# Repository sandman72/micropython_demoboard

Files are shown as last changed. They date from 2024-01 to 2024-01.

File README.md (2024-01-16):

# MicroPython DemoBoard
This repo contains all necessary files for our MicroPython Hardware Workshop at the Attraktor e.V. Makerspace in Hamburg, Germany

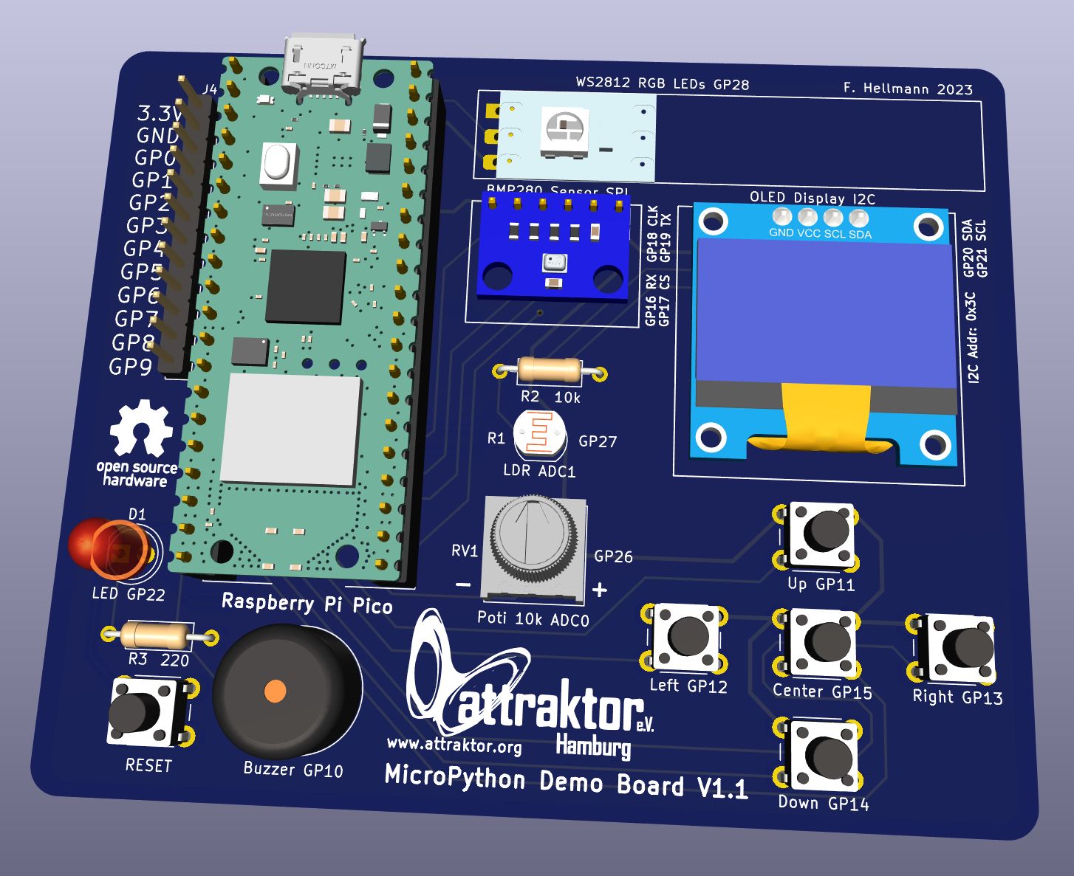
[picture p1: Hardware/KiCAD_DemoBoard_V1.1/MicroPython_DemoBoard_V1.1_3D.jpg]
DemoBoard 3D


You can find the workshop documentation in German here: <a href="https://wiki.attraktor.org/Micropython_Kurs_2023"> Attraktor MicroPython Workshop </a>

### Hardware:
The demoboard works with a Raspberry Pi Pico WH plugged into the pinheaders and connects it to various sensors, buttons, LEDs and an OLED display.

There are two hardware revision to date:

Version 1.0 is the initial version which used an older style of OLED Display with VCC and GND on pins 1 and 2. 

As these old style displays are hard to come by Version 1.1 was spun to change to GND and VCC on pins 1 and 2 as this is a more commonly found pinout of the OLED displays.

I would recommend to use Version 1.1 for all new boards.

You can find an interactive BOM (Bill of Material) here: <a href="https://raw.githack.com/sandman72/micropython_demoboard/main/Hardware/KiCAD_DemoBoard_V1.1/MicroPython_DemoBoard_V1.1_iBOM.html" traget="_blank"> iBOM </a>

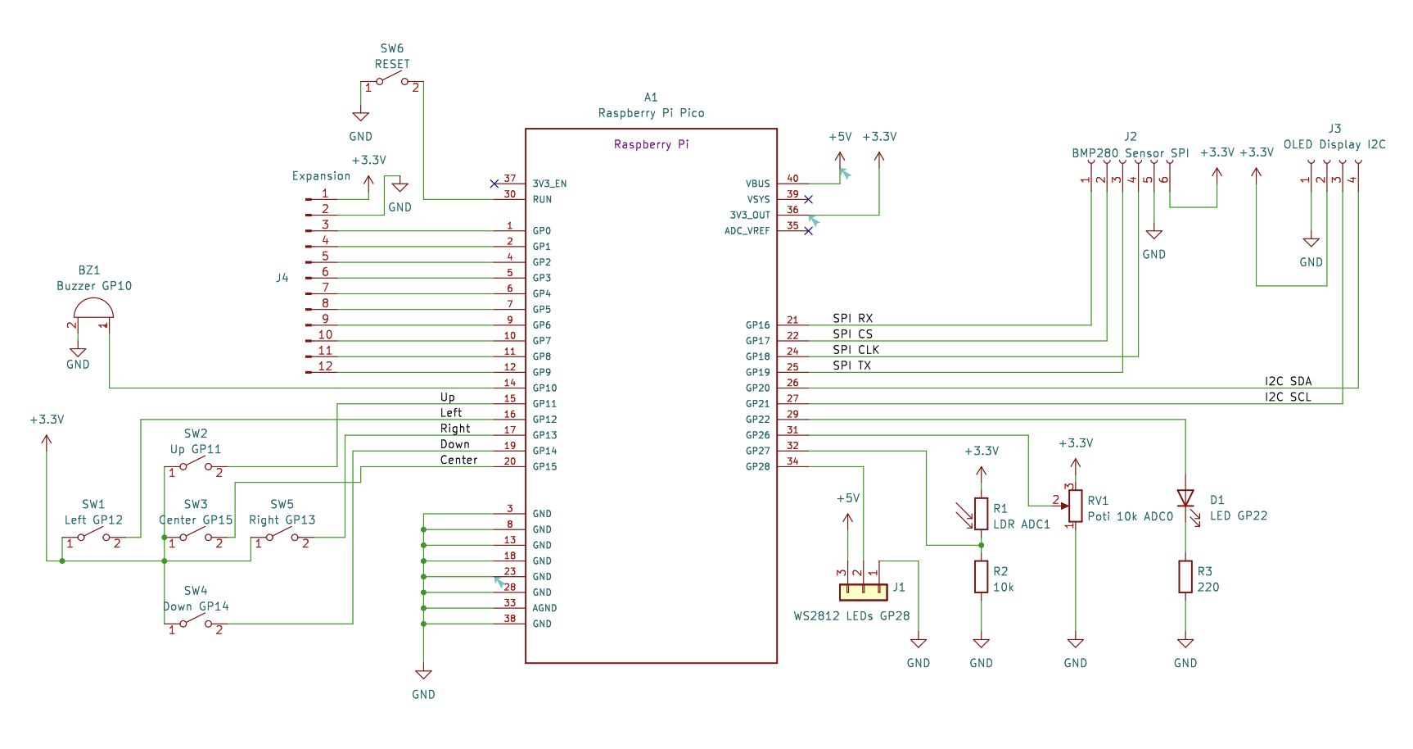
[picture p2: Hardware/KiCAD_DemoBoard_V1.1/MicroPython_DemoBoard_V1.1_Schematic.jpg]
DemoBoard Schematic

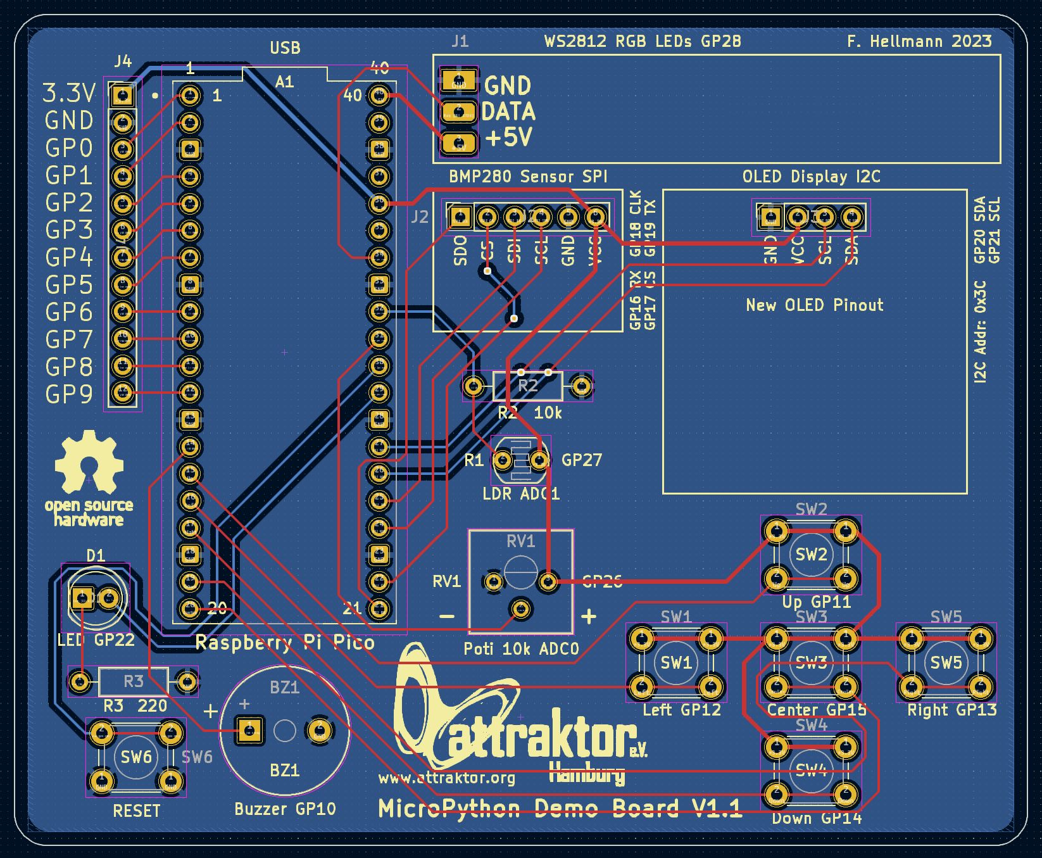
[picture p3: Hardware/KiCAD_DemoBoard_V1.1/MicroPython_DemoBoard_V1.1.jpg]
DemoBoard PCB


### Firmware:
Included in the firmware directory is a board test file and the invaders game as self contained UF2 files.

Simply enter the bootsel mode (hold down the bootsel button, while plugging the Pi Pico in) and copy one for the firmwares over.

### Software:
The software folder contains some demo scripts to try out the different sensors, buttons, buzzer, LEDs and display.

Included are some games like space invaders, flappy bird, snake and pong as well.

Also you'll find the test scripts there.

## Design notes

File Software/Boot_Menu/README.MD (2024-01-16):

# Boot Menü für MicroPython Demo Board

Für den ordnungsgemäßen Betrieb müssen einige Dateien ins Hauptverzeichnis kopiert werden:

boot.py
attraktor_logo.pbm

Flappy_Bird.py
Pong.py 
Snake.py
Space_Invaders.py
Board_Test.py

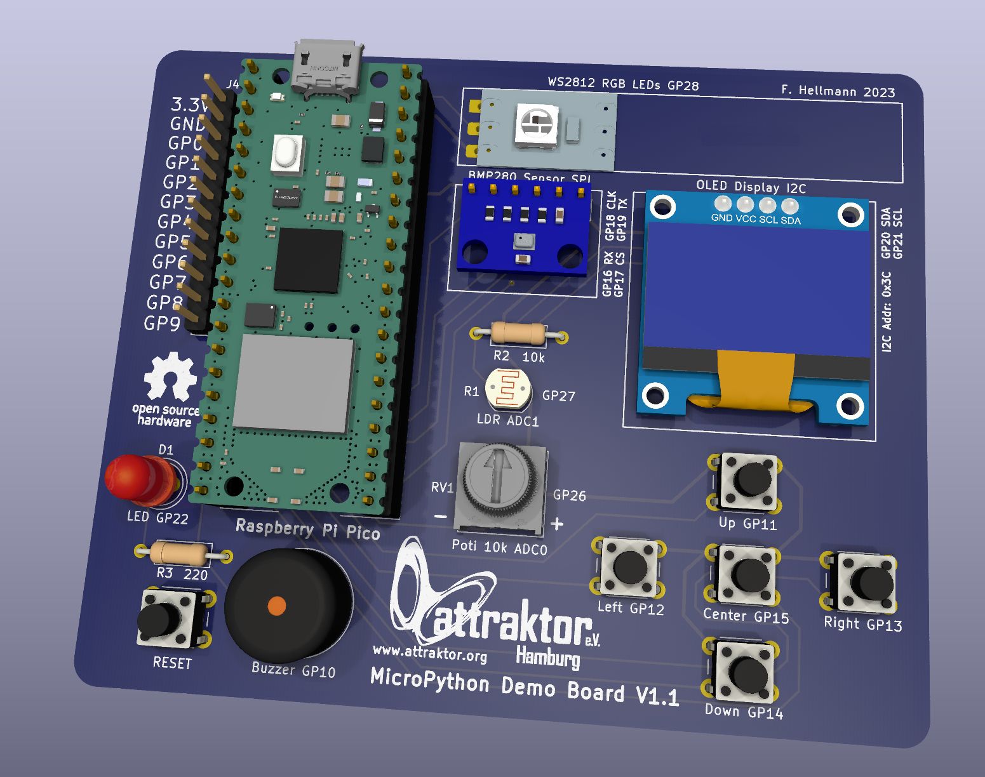
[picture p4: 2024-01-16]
Hardware/KiCAD_DemoBoard_V1.1/MicroPython_DemoBoard_V1.1_3DRT.jpg

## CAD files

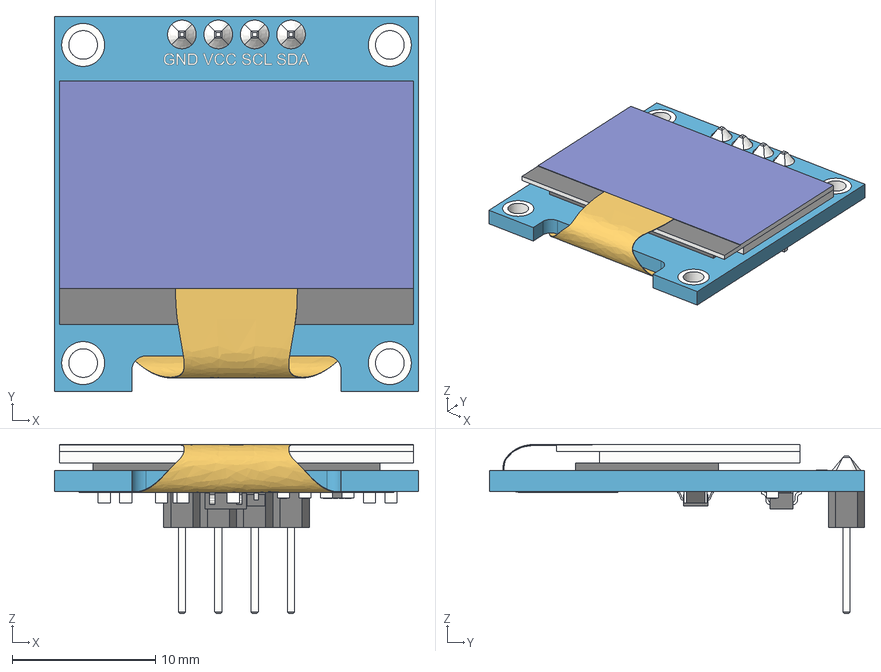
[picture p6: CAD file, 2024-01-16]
Hardware/KiCAD_DemoBoard_V1.1/Modules/SSD1306_OLED_Display(128x64).step
25.4 x 26.2 x 11.8 mm
board
screen
pin_header
soldering
smd_capacitor
smd_capacitor (1)
914_smd_resistor
472_smd_resistor x 3
t4_smd_diode
smd_capacitor (2)
smd_capacitor (3)
smd_capacitor (4)
smd_capacitor (5)
smd_capacitor (6)
472_smd_resistor (1)
SOT-23_XC6206 v3
smd_capacitor (7)
flat_cable

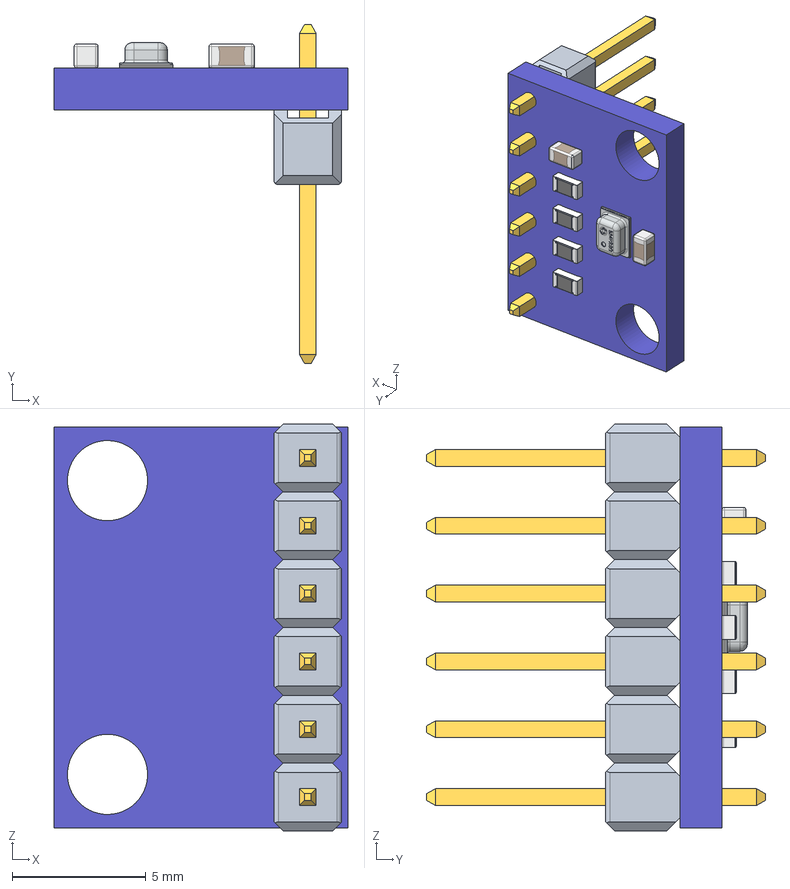
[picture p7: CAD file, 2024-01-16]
Hardware/KiCAD_DemoBoard_V1.1/Modules/BMP280_module.step
11.0 x 12.7 x 15.2 mm

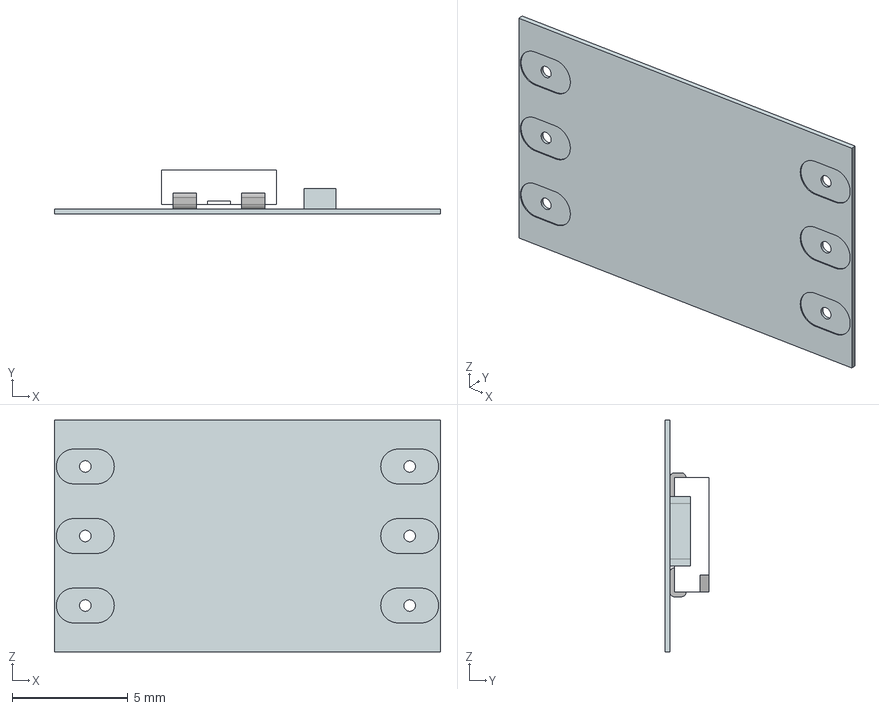
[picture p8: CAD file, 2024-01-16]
Hardware/KiCAD_DemoBoard_V1.1/Modules/WS2812 60 per meter strip.stp
16.7 x 1.92 x 10.0 mm
WS2812_RGB_LED
FlexPCB 60 WS2812 per meter
capacitor_ws2182_strip

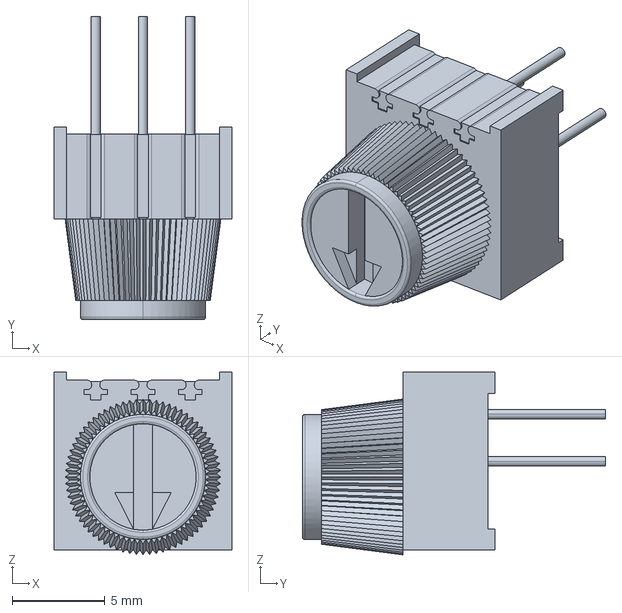
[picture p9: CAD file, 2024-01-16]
Hardware/KiCAD_DemoBoard_V1.1/Modules/3386P.stp
9.58 x 16.3 x 9.83 mm

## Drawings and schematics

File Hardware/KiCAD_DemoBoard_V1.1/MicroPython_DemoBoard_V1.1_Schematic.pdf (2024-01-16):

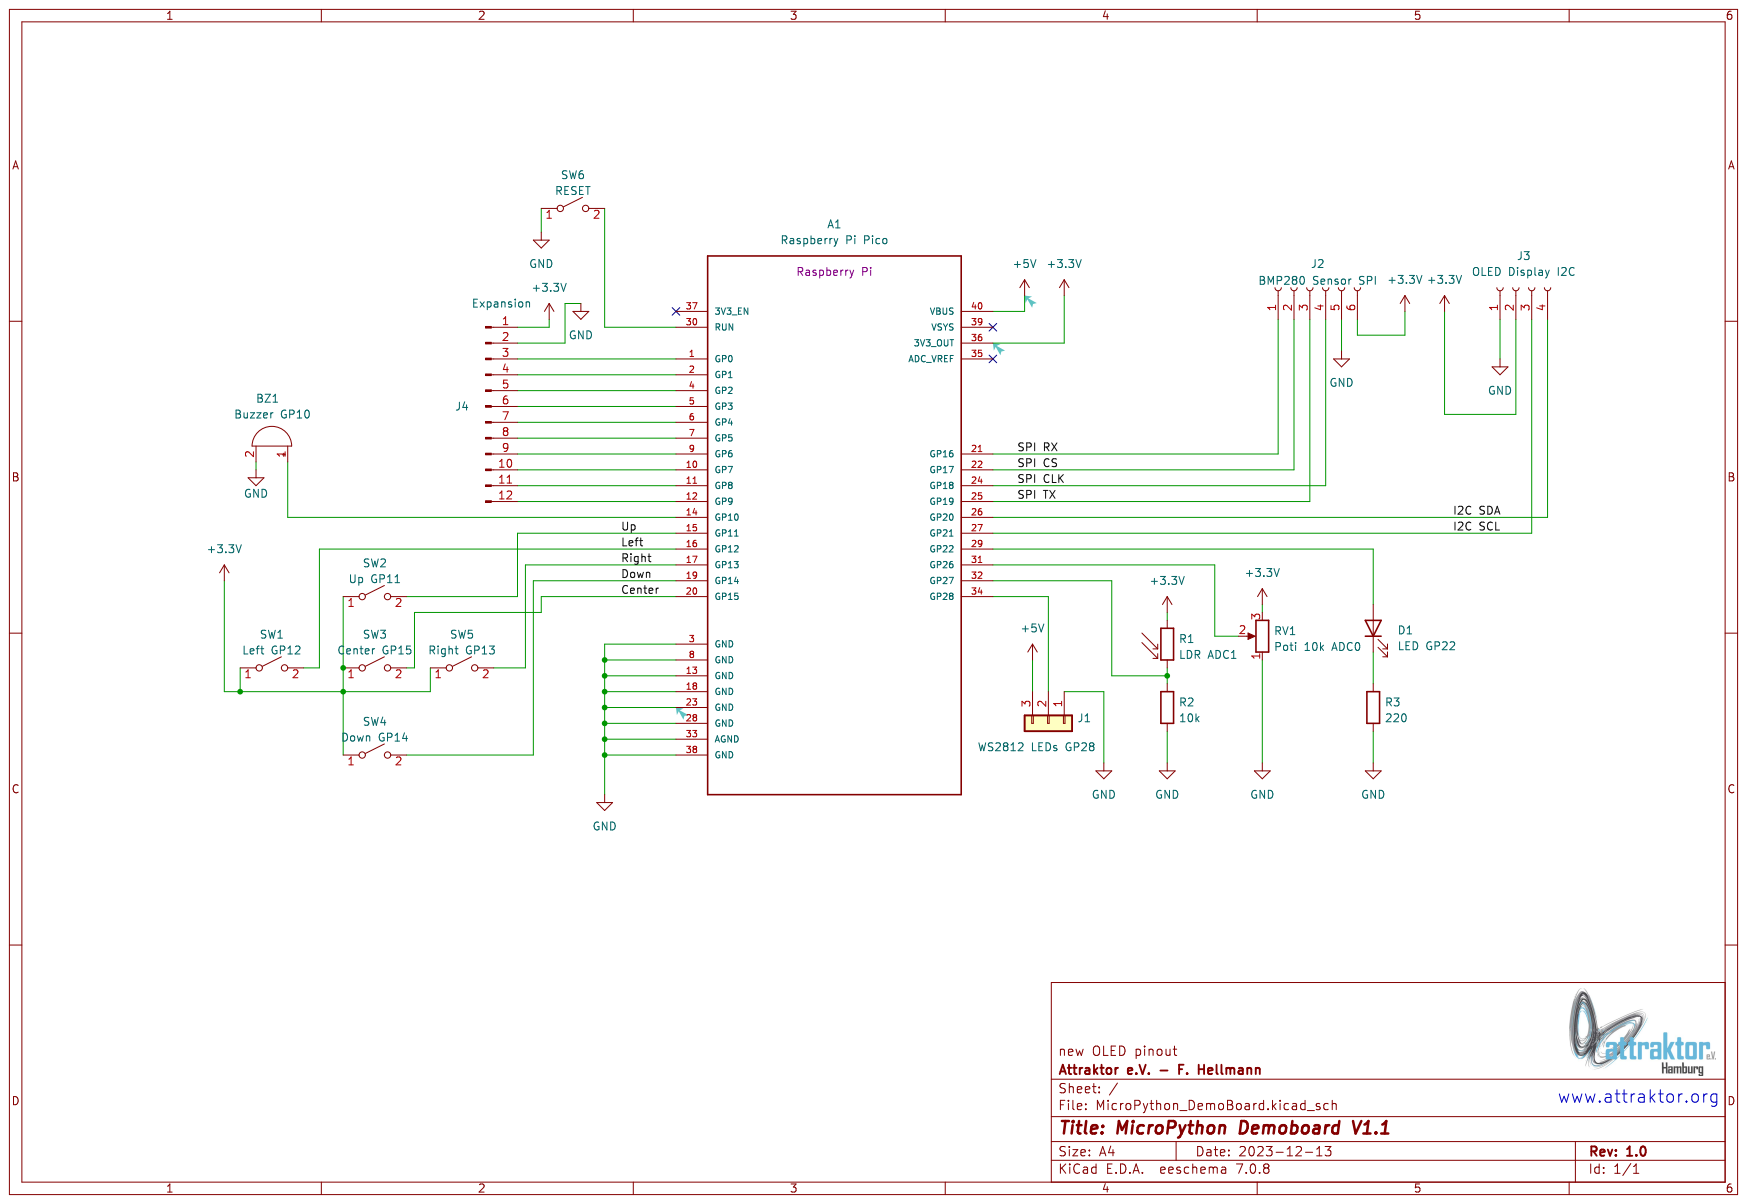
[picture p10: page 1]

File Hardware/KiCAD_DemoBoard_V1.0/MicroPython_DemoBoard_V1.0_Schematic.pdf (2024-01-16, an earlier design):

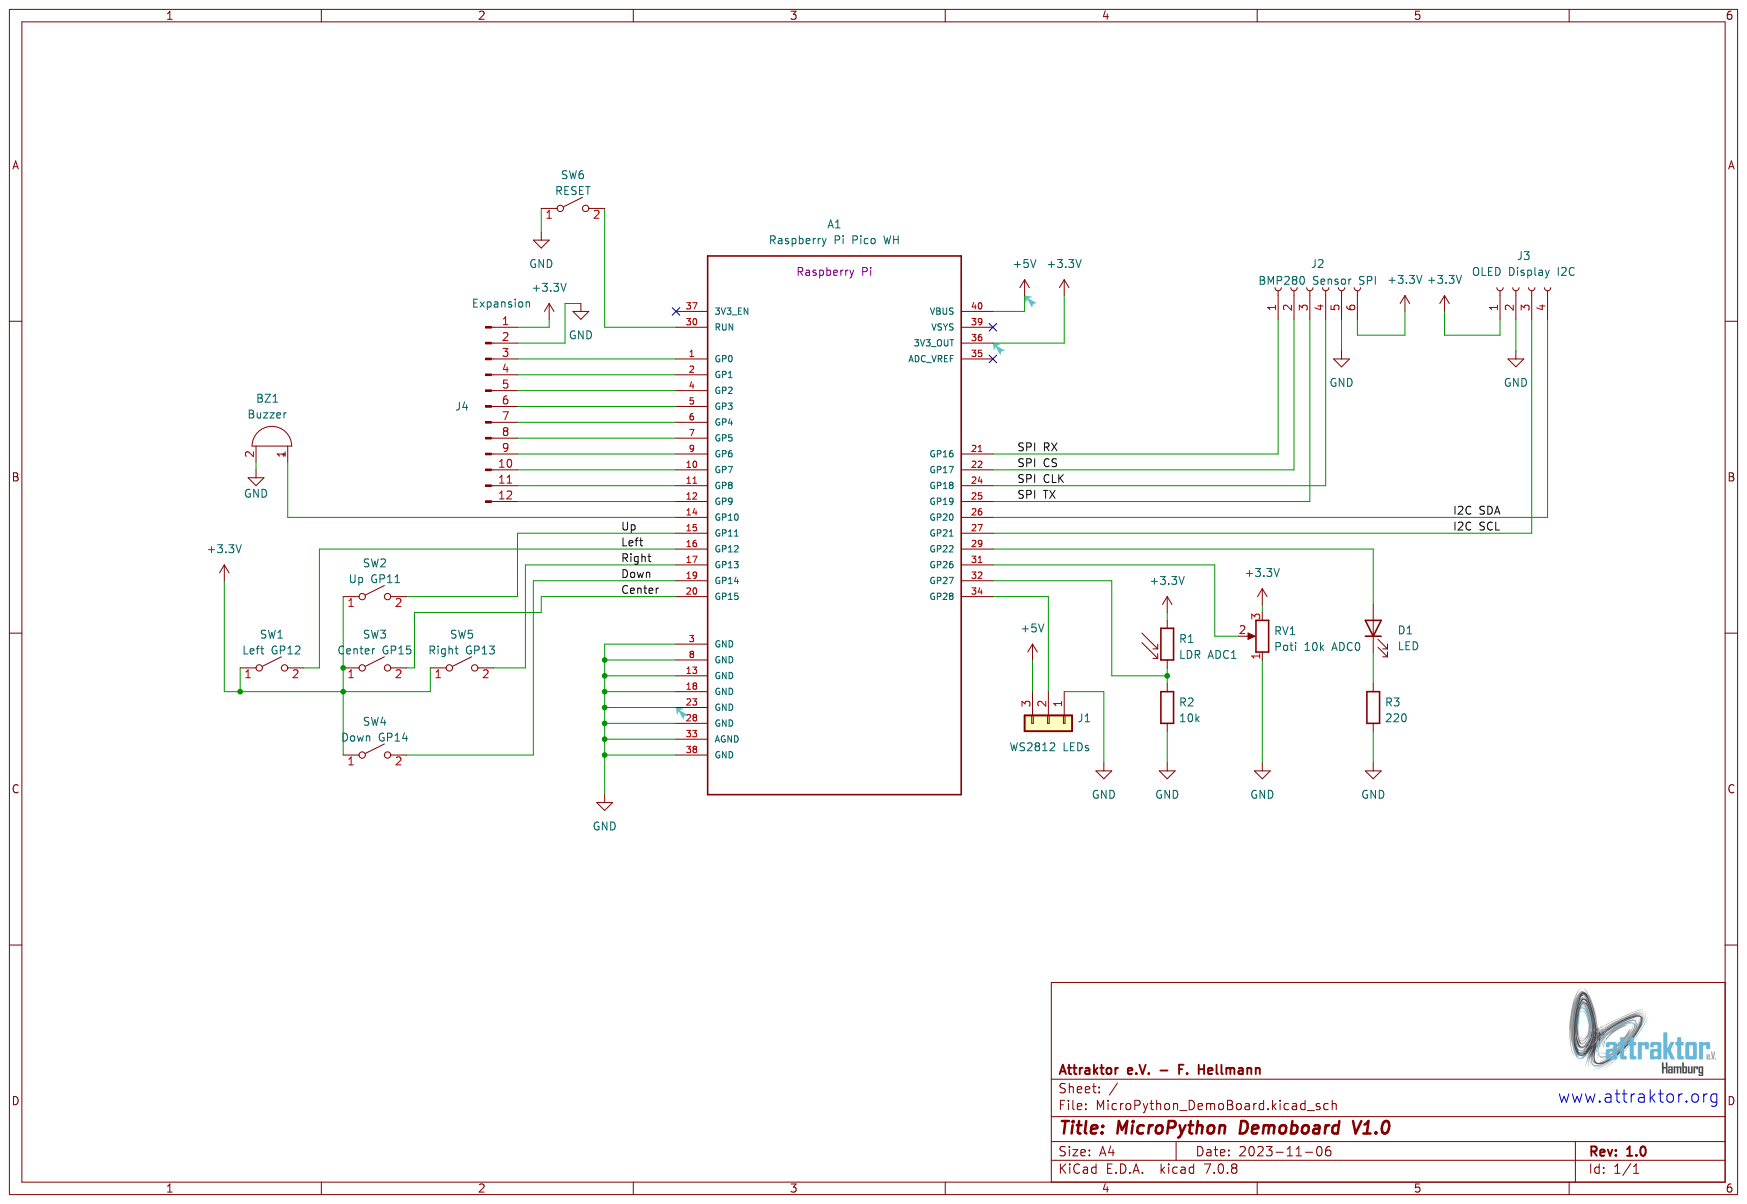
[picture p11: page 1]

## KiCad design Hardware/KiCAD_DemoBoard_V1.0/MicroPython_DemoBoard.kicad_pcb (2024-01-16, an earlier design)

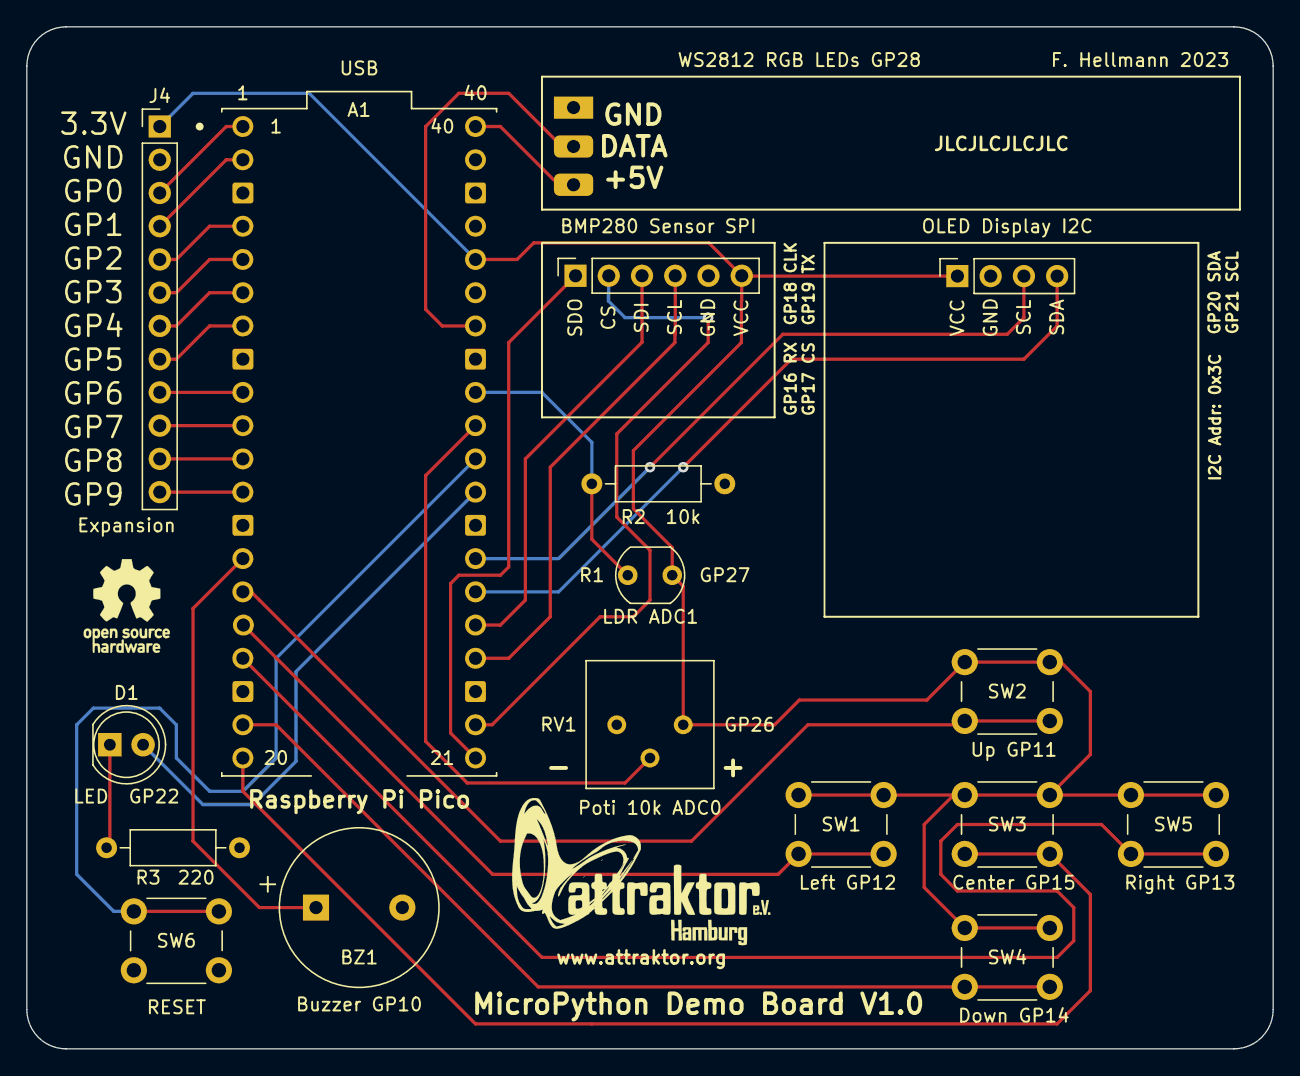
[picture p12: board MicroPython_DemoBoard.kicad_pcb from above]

Board: 2 copper layers, 95.2 x 78.1 mm, 17 parts (0 on the bottom side), 31 nets.

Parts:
A1: Raspberry Pi Pico; Raspberry_Pi_Pico_W_SC0918
BZ1: Buzzer GP10; Buzzer_12x9.5RM7.6
D1: LED GP22; LED_D5.0mm
J1: WS2812 RGB LEDs GP28; PinHeader_1x03_P2.54mm_Vertical
J2: BMP280 Sensor SPI; PinSocket_1x06_P2.54mm_Vertical
J3: OLED Display I2C; PinSocket_1x04_P2.54mm_Vertical
J4: Expansion; PinHeader_1x12_P2.54mm_Vertical
R1: LDR ADC1; R_LDR_5.1x4.3mm_P3.4mm_Vertical
R2: 10k; R_Axial_DIN0207_L6.3mm_D2.5mm_P10.16mm_Horizontal
R3: 220; R_Axial_DIN0207_L6.3mm_D2.5mm_P10.16mm_Horizontal
RV1: Poti 10k ADC0; Potentiometer_Bourns_3386P_Vertical
SW1: Left GP12; SW_PUSH_6mm_H7.3mm
SW2: Up GP11; SW_PUSH_6mm_H7.3mm
SW3: Center GP15; SW_PUSH_6mm_H7.3mm
SW4: Down GP14; SW_PUSH_6mm_H7.3mm
SW5: Right GP13; SW_PUSH_6mm_H7.3mm
SW6: RESET; SW_PUSH_6mm_H7.3mm

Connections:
+3V3: A1.36 (3V3_OUT), J2.6, J3.1, J4.1, R1.1, RV1.3, SW1.1 (A), SW2.1 (A), SW3.1 (A), SW4.1 (A), SW5.1 (A)
+5V: A1.40 (VBUS), J1.3
/Center: A1.20 (GP15), SW3.2 (B)
/Down: A1.19 (GP14), SW4.2 (B)
/I2C SCL: A1.27 (GP21), J3.3
/I2C SDA: A1.26 (GP20), J3.4
/Left: A1.16 (GP12), SW1.2 (B)
/Right: A1.17 (GP13), SW5.2 (B)
/SPI CLK: A1.24 (GP18), J2.4
/SPI CS: A1.22 (GP17), J2.2
/SPI RX: A1.21 (GP16), J2.1
/SPI TX: A1.25 (GP19), J2.3
/Up: A1.15 (GP11), SW2.2 (B)
GND: A1.3 (GND), A1.8 (GND), A1.13 (GND), A1.18 (GND), A1.23 (GND), A1.28 (GND), A1.33 (AGND), A1.38 (GND), BZ1.2 (+), J1.1, J2.5, J3.2, J4.2, R2.2, R3.2, RV1.1, SW6.1 (A)
unnamed: A1.1 (GP0), J4.3
unnamed: A1.2 (GP1), J4.4
unnamed: A1.4 (GP2), J4.5
unnamed: A1.5 (GP3), J4.6
unnamed: A1.6 (GP4), J4.7
unnamed: A1.7 (GP5), J4.8
unnamed: A1.9 (GP6), J4.9
unnamed: A1.10 (GP7), J4.10
unnamed: A1.11 (GP8), J4.11
unnamed: A1.12 (GP9), J4.12
unnamed: A1.14 (GP10), BZ1.1 (-)
unnamed: A1.29 (GP22), D1.2 (A)
unnamed: A1.31 (GP26), RV1.2
unnamed: A1.32 (GP27), R1.2, R2.1
unnamed: A1.34 (GP28), J1.2
unnamed: A1.30 (RUN), SW6.2 (B)
unnamed: D1.1 (K), R3.1

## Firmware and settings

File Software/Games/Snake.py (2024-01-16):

#
# *****     Snake     *****
#
# gespielt wird mit den Buttons
#
# Adaptiert von Frank Hellmann 2023
# für das Attraktor MicroPython Demo Board
#
# Original source code from
# https://github.com/YouMakeTech/PicoRetroGamingSystem
# https://github.com/Twan37/PicoSnake

# Bibliotheken laden
from machine import Pin, PWM, I2C, Timer
import ssd1306
import time
import random

# global variables
SCREEN_WIDTH = 128
SCREEN_HEIGHT = 64

SEGMENT_WIDTH = 8
SEGMENT_PIXELS = int(SCREEN_HEIGHT/SEGMENT_WIDTH)
SEGMENTS_HIGH = int(SCREEN_HEIGHT/SEGMENT_WIDTH)
SEGMENTS_WIDE = int(SCREEN_WIDTH/SEGMENT_WIDTH)
VALID_RANGE = [[int(i /SEGMENTS_HIGH), i % SEGMENTS_HIGH] for i in range(SEGMENTS_WIDE * SEGMENTS_HIGH -1)]

game_timer = Timer()
player = None
food = None

# Initialiere Pins
speaker = PWM(Pin(10))
i2c = I2C(0, sda=Pin(20), scl=Pin(21))
oled = ssd1306.SSD1306_I2C(SCREEN_WIDTH, SCREEN_HEIGHT, i2c)
oled.fill(0)

# Buttons
up = Pin(11, Pin.IN, Pin.PULL_DOWN)
down = Pin(14, Pin.IN, Pin.PULL_DOWN)
left = Pin(12, Pin.IN, Pin.PULL_DOWN)
right = Pin(13, Pin.IN, Pin.PULL_DOWN)
button1 = Pin(15, Pin.IN, Pin.PULL_DOWN)

# Game code
class Snake:
    up = 0
    down = 1
    left = 2
    right = 3
    
    def __init__(self, x=int(SEGMENTS_WIDE/2), y=int(SEGMENTS_HIGH/2) + 1):
        self.segments = [[x, y]]
        self.x = x
        self.y = y
        self.dir = random.randint(0,3)
        self.state = True
        
    def reset(self, x=int(SEGMENTS_WIDE/2), y=int(SEGMENTS_HIGH/2) + 1):
        self.segments = [[x, y]]
        self.x = x
        self.y = y
        self.dir = random.randint(0,3)
        self.state = True
        
    def move(self):
        new_x = self.x
        new_y = self.y
        
        if self.dir == Snake.up:
            new_y -= 1
        elif self.dir == Snake.down:
            new_y += 1
        elif self.dir == Snake.left:
            new_x -= 1
        elif self.dir == Snake.right:
            new_x += 1
        
        for i, _ in enumerate(self.segments):
            if i != len(self.segments) - 1:
                self.segments[i][0] = self.segments[i+1][0]
                self.segments[i][1] = self.segments[i+1][1]
        
        if self._check_crash(new_x, new_y):
            # Oh no, we killed the snake :C
            if self.state == True:
                # play an ugly sound
                speaker.freq(200)
                speaker.duty_u16(2000)
                time.sleep(0.5)
                speaker.duty_u16(0)
            self.state = False
        
        self.x = new_x
        self.y = new_y
        
        self.segments[-1][0] = self.x
        self.segments[-1][1] = self.y
        
    def eat(self):
        oled.fill_rect(self.x * SEGMENT_PIXELS, self.y * SEGMENT_PIXELS, SEGMENT_PIXELS, SEGMENT_PIXELS, 0)
        oled.rect(self.x * SEGMENT_PIXELS, self.y * SEGMENT_PIXELS, SEGMENT_PIXELS, SEGMENT_PIXELS, 1)
        self.segments.append([self.x, self.y])
        # Make a sound
        speaker.freq(1000)
        speaker.duty_u16(2000)
        time.sleep(0.100)
        speaker.duty_u16(0)
        
    def change_dir(self, dir):
        if  dir == Snake.down and self.dir == Snake.up:
            return False
        
        elif dir == Snake.up and self.dir == Snake.down:
            return False
        
        elif dir == Snake.right and self.dir == Snake.left:
            return False
        
        elif dir == Snake.left and self.dir == Snake.right:
            return False
        
        self.dir = dir
        
    def _check_crash(self, new_x, new_y):
        if new_y >= SEGMENTS_HIGH or new_y < 0 or new_x >= SEGMENTS_WIDE or new_x < 0 or [new_x, new_y] in self.segments:
            return True
        else:
            return False
    
    def draw(self):
        oled.rect(self.segments[-1][0] * SEGMENT_PIXELS, self.segments[-1][1] * SEGMENT_PIXELS, SEGMENT_PIXELS, SEGMENT_PIXELS, 1)

def update_game(timer):
    global food
    global player
    
    # Remove the previous tail of the snake (more effecient than clearing the entire screen and redrawing everything)
    oled.fill_rect(player.segments[0][0] * SEGMENT_PIXELS, player.segments[0][1] * SEGMENT_PIXELS, SEGMENT_PIXELS, SEGMENT_PIXELS, 0)
    
    # Move the snake
    player.move()
    
    if player.state == True:
        # Our snake is still alive and moving
        if food[0] == player.x and food[1] == player.y:
            # Our snake reached the food
            player.eat()
            food = random.choice([coord for coord in VALID_RANGE if coord not in player.segments])
            oled.fill_rect(food[0] * SEGMENT_PIXELS , food[1] * SEGMENT_PIXELS, SEGMENT_PIXELS, SEGMENT_PIXELS, 1)
        
        player.draw()
        
    # Show the new frame
    oled.rect(0,0,SCREEN_WIDTH,SCREEN_HEIGHT,1)
    oled.show()

def pico_snake_main():
    global player
    global food
    
    player = Snake()
    food = random.choice([coord for coord in VALID_RANGE if coord not in player.segments])
    oled.fill_rect(food[0] * SEGMENT_PIXELS , food[1] * SEGMENT_PIXELS, SEGMENT_PIXELS, SEGMENT_PIXELS, 1)
    
    # Playing around with this cool timer.
    game_timer.init(freq=5, mode=Timer.PERIODIC, callback=update_game)
    
    while True:
        if player.state == True:
            # If the snake is alive
            if up.value() == 1:
                    player.change_dir(Snake.up)
                    
            elif right.value() == 1:
                    player.change_dir(Snake.right)
                    
            elif left.value() == 1:
                    player.change_dir(Snake.left)
                    
            elif down.value() == 1:
                    player.change_dir(Snake.down)
        
        else:
            # The snake is dead
            
            # disable the timer
            game_timer.deinit()
            
            # display Game Over
            oled.fill(0)
            oled.text("Game Over!" , int(SCREEN_WIDTH/2) - int(len("Game Over!")/2 * 8), int(SCREEN_HEIGHT/2) - 8)
            oled.text("Snake length:" + str(len(player.segments)) , int(SCREEN_WIDTH/2) - int(len("Snake length:" + str(len(player.segments))) /2 * 8), int(SCREEN_HEIGHT/2) + 16)
            oled.show()
            
            # wait for a button
            while button1.value()==0:
                time.sleep(0.01)
            
            # exit the loop and restart the game
            oled.fill(0)
            break
                
while True:
    pico_snake_main()

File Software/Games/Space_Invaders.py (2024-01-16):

# PicoInvaders.py by Vincent Mistler (YouMakeTech)
# A simplified Space Invaders game
# for the Rapsberry Pi Pico RetroGaming Console
#
# The code is far from perfect but it works!
#
# Adapted to the Attraktor MicroPython Demo Board
# by Frank Hellmann 11.2023
#
# Original Code:
# https://github.com/YouMakeTech/PicoRetroGamingSystem
#

# Bibliotheken importieren
from PicoGame import PicoGame
import time
import random

def intersect(x1, y1, w1, h1, x2, y2, w2, h2):
    # return true if the 2 rectangles
    # (x1,y1,w1,h1) and (x2,y2,w2,h2) overlaps
    # this is used to detect collisions between sprites
    overlap = True
    if x2 > x1 + w1 - 1:
        overlap = False
    if x2 + w2 - 1 < x1:
        overlap = False
    if y2 > y1 + h1 -1:
        overlap = False
    if y2 + h2 -1 < y1:
        overlap = False
    return overlap

class Alien:
    # Alien states (constants)
    DEAD = 0       
    DISAPPEARING = 1
    EXPLODING = 2
    ALIVE = 3
    
    def __init__(self, x, y, sprite):
        self.x = x     # position of the alien on the screen
        self.y = y
        self.sprite = sprite # sprite number
        self.state = Alien.ALIVE
    
    def switch_sprite(self):
        # switch between sprites to animate aliens
        if self.sprite<3:
            self.sprite+=3
        else:
            self.sprite-=3

class Laser:
    def __init__(self, width, height):
        # initialize laser starting coordinates
        # from ship coordinates
        self.width = width
        self.height = height
        self.x = -1         # laser position on screen
        self.y = -1
        self.x0 = -1        # ship position when firing
        self.y0 = -1
        self.active = False # True whe a laser is displayed
        self.released = False   # True once right after firing
        
    def fire(self, x0, y0):
        if not self.active:
            self.x0 = x0
            self.y0 = y0
            self.x = x0 + 5
            self.y = y0
            self.active = True
        
    def move(self, vy):
        if self.active:
            self.y += vy
            if self.y < 0:
                self.active = False
            
    def draw(self, game):
        if self.active:
            game.fill_rect(int(self.x), int(self.y), self.width, self.height, 1)
    
class Ufo:
    # UFO states (constants)
    DEAD = 0       
    DISAPPEARING = 1
    EXPLODING = 2
    ALIVE = 3
    
    def __init__(self):
        self.x = -1     # position of the ufo on the screen
        self.y = -1
        self.state = Ufo.DEAD
        
    def move(self, vx):
        # move the UFO towards the right of the screen
        # at speed vx
        self.x += vx
        if self.x > 128:
            self.state = Ufo.DEAD

def init_aliens(ALIENS_ROWS,ALIENS_COLS,ALIENS_INIT_X,ALIENS_INIT_Y,ALIENS_SPACING_X,ALIENS_SPACING_Y):
    # initialize aliens
    aliens = []
    sprite = 0
    for i in range(ALIENS_ROWS):
        for j in range(ALIENS_COLS):
            x = ALIENS_INIT_X + j * ALIENS_SPACING_X
            y = ALIENS_INIT_Y + i * ALIENS_SPACING_Y
            alien = Alien(x, y, min(i,2))
            aliens.append(alien)
    return aliens

def pico_invaders_main():
    # Pico Invaders main
    
    game = PicoGame()
    
    # Sprites graphics definition
    ALIEN1A_W = 8    # width and height of the sprite in pixels
    ALIEN1A_H = 8
    ALIEN1A = bytearray([0b00011000,
                         0b00111100,
                         0b01111110,
                         0b11011011,
                         0b11111111,
                         0b00100100,
                         0b01011010,
                         0b10100101])

    ALIEN1B_W = 8
    ALIEN1B_H = 8
    ALIEN1B = bytearray([0b00011000,
                         0b00111100,
                         0b01111110,
                         0b11011011,
                         0b11111111,
                         0b01011010,
                         0b10000001,
                         0b01000010])


    ALIEN2A_W = 11
    ALIEN2A_H = 8
    ALIEN2A = bytearray([0b00100000,0b10000000,
                         0b00010001,0b00000000,
                         0b00111111,0b10000000,
                         0b01101110,0b11000000,
                         0b11111111,0b11100000,
                         0b10111111,0b10100000,
                         0b10100000,0b10100000,
                         0b00011011,0b00000000])

    ALIEN2B_W = 11
    ALIEN2B_H = 8
    ALIEN2B = bytearray([0b00100000,0b10000000,
                         0b10010001,0b00100000,
                         0b10111111,0b10100000,
                         0b11101110,0b11100000,
                         0b11111111,0b11100000,
                         0b00111111,0b10000000,
                         0b00100000,0b10000000,
                         0b01000000,0b01000000])

    ALIEN3A_W = 12
    ALIEN3A_H = 8
    ALIEN3A = bytearray([0b00001111,0b00000000,
                         0b01111111,0b11100000,
                         0b11111111,0b11110000,
                         0b11100110,0b01110000,
                         0b11111111,0b11110000,
                         0b00011001,0b10000000,
                         0b00110110,0b11000000,
                         0b11000000,0b00110000])

    ALIEN3B_W = 12
    ALIEN3B_H = 8
    ALIEN3B = bytearray([0b00001111,0b00000000,
                         0b01111111,0b11100000,
                         0b11111111,0b11110000,
                         0b11100110,0b01110000,
                         0b11111111,0b11110000,
                         0b00011001,0b10000000,
                         0b00110110,0b11000000,
                         0b00011001,0b10000000])

    PLAYER_W = 11
    PLAYER_H = 8
    PLAYER = bytearray([0b00000100,0b00000000,
                        0b00001110,0b00000000,
                        0b00001110,0b00000000,
                        0b01111111,0b11000000,
                        0b11111111,0b11100000,
                        0b11111111,0b11100000,
                        0b11111111,0b11100000,
                        0b11111111,0b11100000])

    LASER_W = 1
    LASER_H = 8
    LASER = bytearray([0b00000100,
                       0b00000100,
                       0b00000100,
                       0b00000100,
                       0b00000100,
                       0b00000100,
                       0b00000100,
                       0b00000100])

    EXPLOSION_W = 12
    EXPLOSION_H = 7
    EXPLOSION = bytearray([0b00001000,0b10000000,
                           0b01000101,0b00010000,
                           0b00100000,0b00100000,
                           0b00010000,0b01000000,
                           0b11000000,0b00011000,
                           0b00010000,0b01000000,
                           0b00100101,0b00100000,
                           0b01001000,0b10010000])
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

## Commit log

2024-01-16 added files to repository
    first commit with
    hardware V1.0 (old OLED pinout) and V1.1 (new OLED pinout)
    software V1.0
    firmware V1.0 with board test and invader game
    [3386P.stp, BMP280_module.step, MicroPython_DemoBoard.kicad_pcb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]
2024-01-16 Added Boot Menu
    Added Boot Menu for Games and Board Test.
2024-01-17 Update Flappy_Bird.py
    fixed bug: high_score variable not set on first run
    [Flappy_Bird.py]
2024-01-17 Add files via upload
    Firmware with bootloader for the FabCity e.V. boards
